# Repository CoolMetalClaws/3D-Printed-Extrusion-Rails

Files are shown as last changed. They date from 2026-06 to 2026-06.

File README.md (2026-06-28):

# ModuRail: A Modular 3D Printed 2020 V-Slot Extrusion Rail System

Extrusion Rails

## Overview

This project features a Modular 2020 V-Slot Extrusion rail System along with its parts/attachments. The parts include connectors, feet, and sliding parts. All aspects of the design were created in Onshape. 

##  Features

- Snap fit connectors and smooth movement for high modularity
- Full compatibility with all 2020 V-Slot extrusion rails and their accessories
- Quick printing for small DIY projects
- Minimal material usage for quality output
- All parts designed with print tolerances for smoother movement
- STEP files provided for ONLY for slider to allow modification 
- Super Glue (Cyanoacrylate) can be used for a permanant fix between parts
- 0.2mm print tolerances allow it to be printed on almost all printers
- Ease of assembly 

DISCLAIMER: Do not use 3D printed rails for any serious/industrial applictions or in industrial machinery where failure has the potential to cause harm and losses.

## Parts

### 1. 2020 V-Slot Extrusion Rail 100mm Length (Compatible for most printers)

Extrusion Rails

Multiple rails can be connected in series using connectors if larger lengths required. 3D printed rails are compatible with commercially available ones. 

### 2. Extrusion Rail Feet 

Extrusion Rails

Are slid on beneath the rails for added height and a stable surface. Can be superglued in place for a permanant fix.

### 3. Extrusion Rail End Cap

Extrusion Rails

Are used to stop rails from sliding off and to provide a better and cleaner end finish. Can be superglued in place for a permanant fix.

### 4. Extrusion Rail Slider (STEP file available)

Extrusion Rails

Are used to have parts, attachments and accessories slide, and are useful when making projects with functional moving paths that require a guided rail path. A STEP file is available for uses that require customised sliders.

### 5. Extrusion Rail Connectors

Extrusion Rails

Are used to connect multiple rails together for uses that require larger lengths. Can be superglued in place for a permanant fix.

## 3D Printing Settings

### Material :

 PETG or ABS recommended for structural parts that are under constant use, use PLA for prototyping and genral projects. Ensure fillament is completely dry before printing to ensure part sizing and fit, as bubbling may cause an uneven surface and a smaller/larger end product.

### Infill : 

60%+ infill recommended for structural applications, while 15-30% will work for common projects that do no require much strain. Recommended infill type is Gyroid or Tri-Hexagon infill for structural parts.

### Outer Walls : 

4-5 outer walls recommended for structural parts that are under constant use, while 3 walls work well for all other uses.

### Supports : 

None of the parts require any supports, though a brim may be required for the rails if printing vertically to ensure it doesn't fall over.

## Assembly

### 1. 

Clean up the 3D printed parts (Remove brims and stringing if visible) 

### 2. End Cap: 

The end cap slides into either open end of any 2020 V-slot Extrusion, as per required. It can be superglued in place for a permanent fix .See image below for example:

Extrusion Rails

### 3. Rail Connectors: 

The connectors are inserted into the central holes of the both rails that require connection. They can be superglued in place for a permanent fix. See image below for example:

Extrusion Rails

### 4. Feet:

The feet are slid onto the base of the rail for stablility and for a slightly increased height. See image below for example:

Extrusion Rails

## License 

This design is under the Creative Commons Attribution-NonCommercial (CC BY-NC) licence. This design or any of its derivatives can be used only for personal use and cannot be sold. Users are free to create remixes with proper attribution to the creator, but cannot make money of them.

## Link to original design

https://cad.onshape.com/documents/22113442d805ee37a19f0e13/w/2d82247462f69fdc68fc0b5b/e/f6fcab689193597269c9dd49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

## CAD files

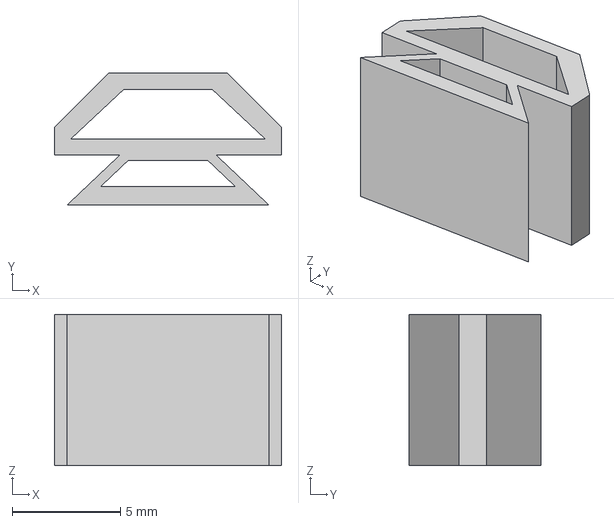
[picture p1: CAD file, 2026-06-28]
2020 Extrusion Rail Slider STEP FILE.step
10.5 x 6.10 x 7.00 mm

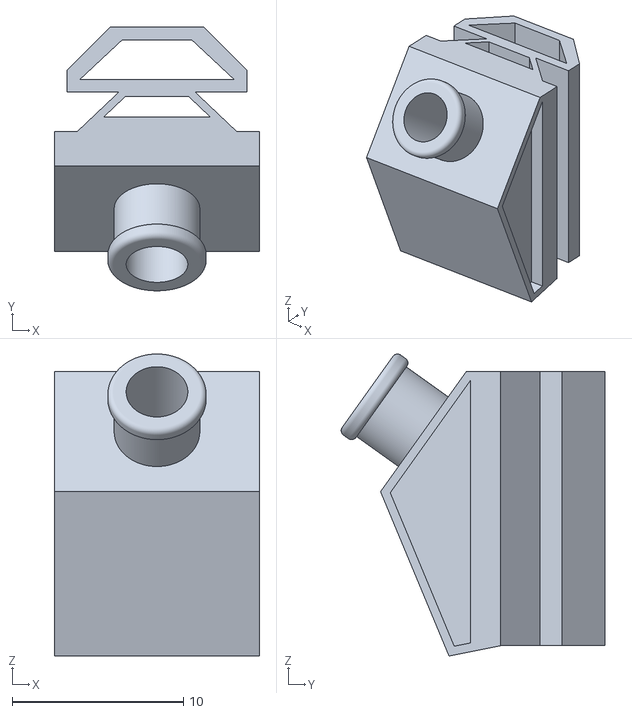
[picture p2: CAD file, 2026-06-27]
2020 Extrusion Rail Sliding Car V2.stl
12.0 x 15.4 x 17.6

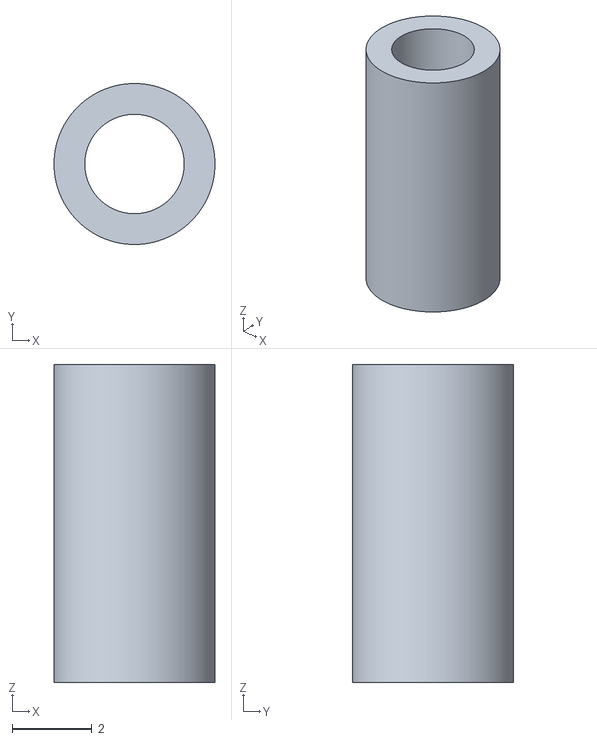
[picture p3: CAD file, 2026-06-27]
2020 Extrusion Rail Connector Part 1 V2.stl
4.05 x 4.05 x 8.00

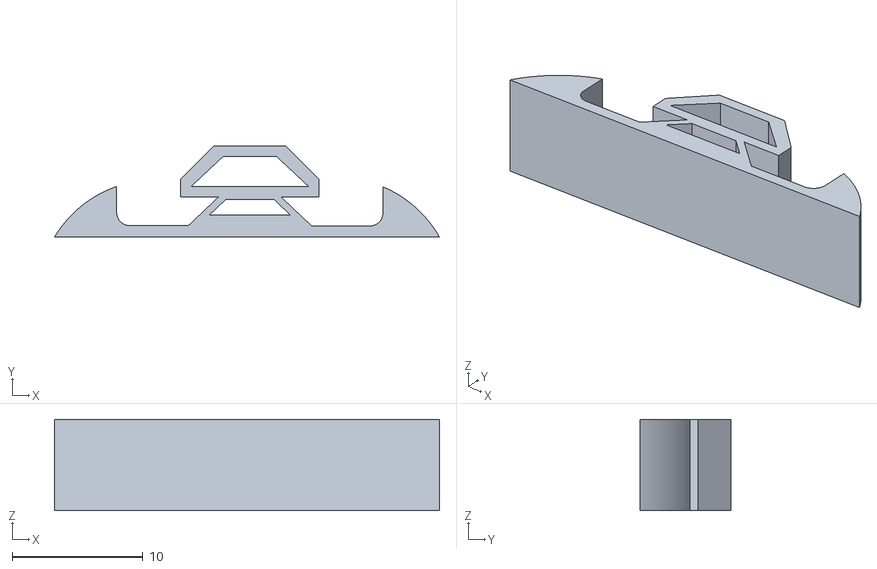
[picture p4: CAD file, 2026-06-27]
2020 Extrusion Rail Feet V2.stl
29.5 x 6.98 x 7.00

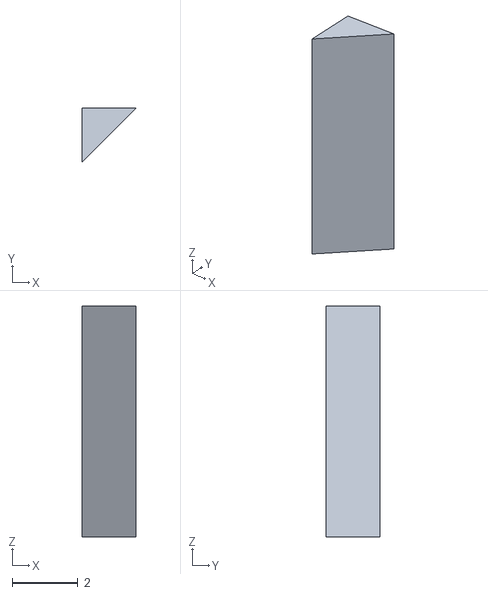
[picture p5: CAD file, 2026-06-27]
2020 Extrusion Rail Connector Part 2.stl
1.65 x 1.65 x 7.00

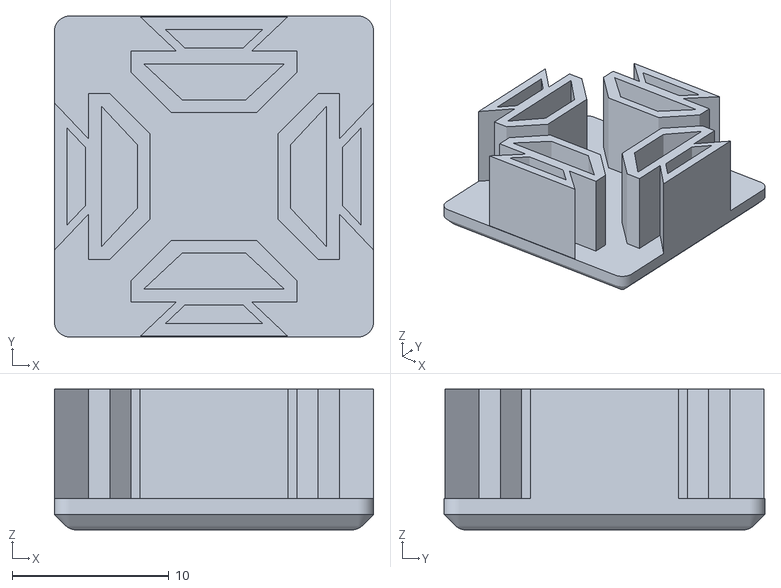
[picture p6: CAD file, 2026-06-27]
2020 Extrusion Rail End Cap V2.stl
20.4 x 20.5 x 9.00

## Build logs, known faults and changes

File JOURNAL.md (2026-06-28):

# Engineering Journal for ModuRail: A Modular 3D Printed 2020 V-Slot Extrusion Rail System

## Problem: 

I required extrusion rails for a project, and all available ones were expensive and with long shipping times. I decided that printing them would be a more cost effective and easy way to use them for my application.

## Day 1 (2hrs 13mins) : 

I Fully sketched out and extruded the end face of an extrusion rail using an official orthogonal sketch with dimensions. This ensured accuracy and compatability with cmmercially sold extrusion rails. The end face was extremely complicated to sketch and took a while, but the end result has accurate dimensions. I began to sketch the sliders for the rails with an exact fit.

## Day 2 (1hr 46mins) :

I completed sketching and extruding the sliders, the feet, and the connectors. All parts were labelled for clarity and organisation, as all the tabs were confusing to keep a track of. To make the end peice, i simply duplicated the sliders 4 times around the same axis. Then, i sketched a base for them all to connect to, completing all the parts.

## Day 3 (1hr 32mins) : 

I 3D printed all nessecary sections required to test the fitting between parts. Unfortunately none of the parts fit, as i realised i forgot to account for PLA shrinkage. I altered all parts to have a 0.2 mm tolerance, which is universal for most printers. After reprinting all parts, the feet were too loose and kept sliding around, but they were meant to be stationary. I adjusted the feet print tolerances to 0.12mm, making it perfectly tight. 

## Day 4 (2hrs 35mins) :

I wrote a proper, detailed README and JOURNAL to upload my completed project.

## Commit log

2026-06-27 Added files for the extrusion rails and its parts
    [2020 Extrusion Rail Connector Part 1 V2.stl, 2020 Extrusion Rail Connector Part 2.stl, 2020 Extrusion Rail End Cap V2.stl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]
2026-06-28 Added STEP file for rail slider
    This allows for more customisability for the user, allowing custom sliders for own projects
    [2020 Extrusion Rail Slider STEP FILE.step]
2026-06-28 Revise README for ModuRail project
    Updated project name and enhanced README content with features, parts, 3D printing settings, assembly instructions, and licensing information.
2026-06-28 Add engineering journal for ModuRail project
    Documented the engineering process for creating a modular 3D printed extrusion rail system, including sketches, designs, and adjustments made during testing.
